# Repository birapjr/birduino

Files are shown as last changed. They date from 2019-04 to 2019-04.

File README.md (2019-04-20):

# birduino
Prototype board for common projects

Current version: 1.1

The PCB images:

3D view

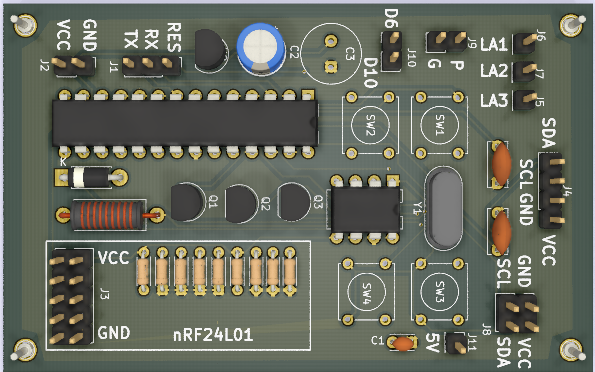
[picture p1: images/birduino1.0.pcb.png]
birduino 1.0 PCB


Front

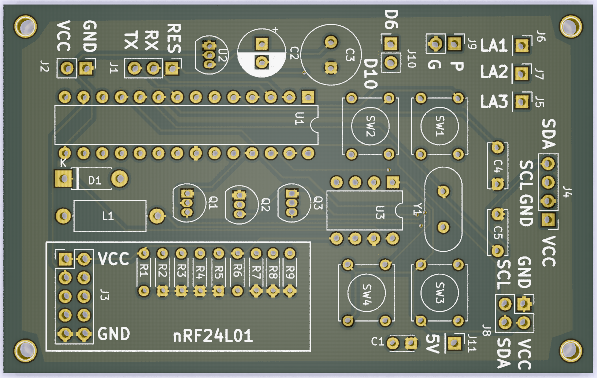
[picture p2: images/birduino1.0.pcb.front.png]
birduino 1.0 PCB front


Back

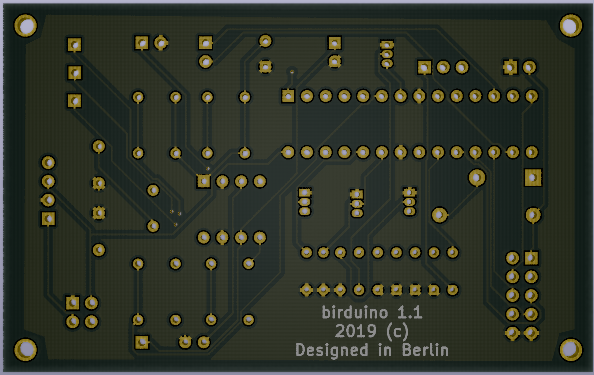
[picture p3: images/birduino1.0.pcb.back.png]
birduino 1.0 PCB back


Main features:

  * Microcontroller: ATMEGA328
  * Main voltage: 3.7 V
  * Radio card: nRF24L01
  * Sensor: Temperature DS18B20
  * Display: OLED
  * Buttons: 4
  * Setup output: 5V
  * Power controls: 3 MOSFET 2N7000
  * Analog reader: 1 pin at J9
  * Free pins: 2, D6 and D10
  * Programming: Onboard serial programming

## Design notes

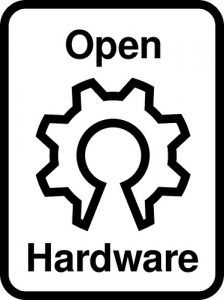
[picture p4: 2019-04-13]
images/OpenHardware.jpg

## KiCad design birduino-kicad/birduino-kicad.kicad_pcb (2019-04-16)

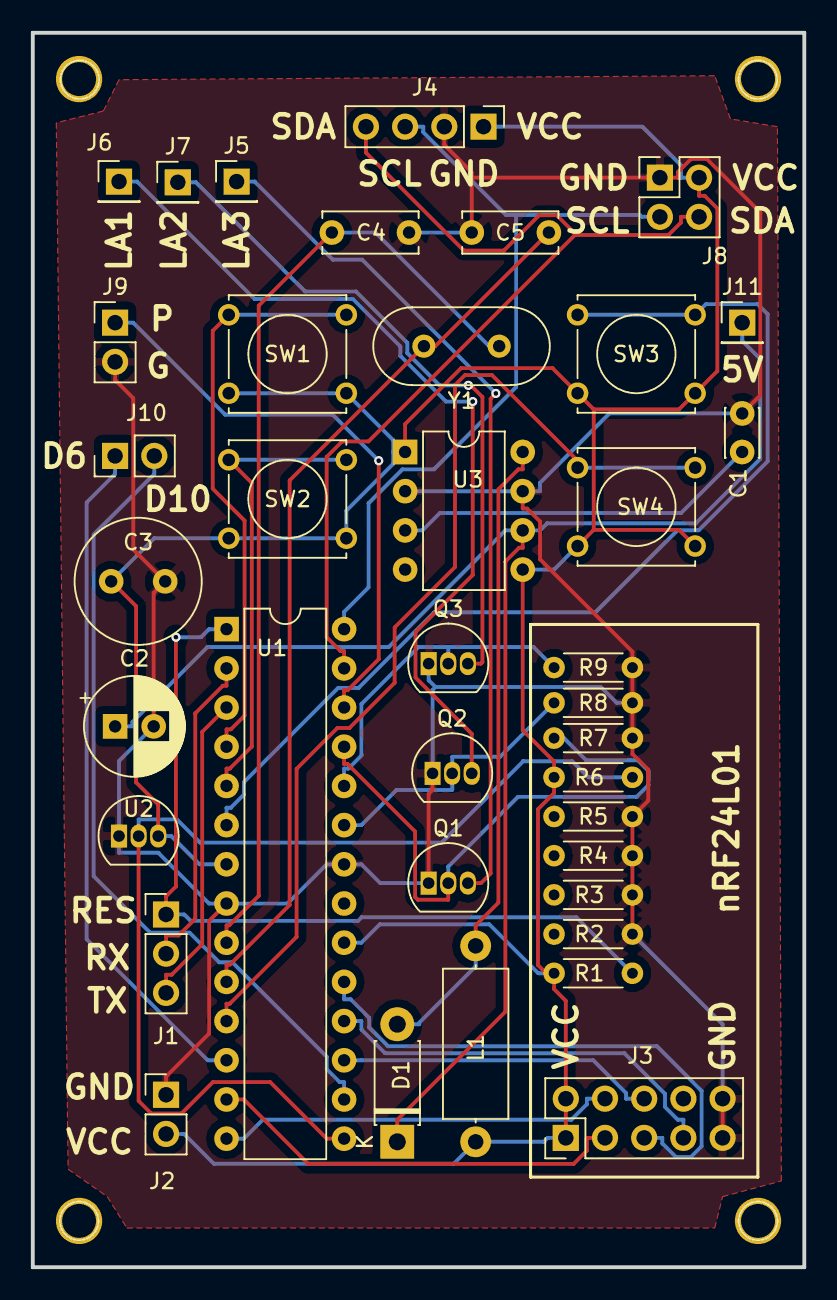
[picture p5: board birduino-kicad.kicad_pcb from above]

Board: 2 copper layers, 50.0 x 80.0 mm, 38 parts (0 on the bottom side), 31 nets.

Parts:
C1: 0.1uF; C_Disc_D3.0mm_W2.0mm_P2.50mm
C2: 100uF; CP_Radial_D6.3mm_P2.50mm
C3: 150uF; C_Radial_D8.0mm_H7.0mm_P3.50mm
C4, C5: 22uF; C_Disc_D6.0mm_W2.5mm_P5.00mm
D1: 1N5817; D_DO-41_SOD81_P7.62mm_Horizontal
J1: Conn_01x03_Male; PinHeader_1x03_P2.54mm_Vertical
J2, J10: Conn_01x02_Male; PinHeader_1x02_P2.54mm_Vertical
J3: Conn_02x05_Odd_Even; PinHeader_2x05_P2.54mm_Vertical
J4: Conn_01x04; PinHeader_1x04_P2.54mm_Vertical
J5, J6, J7, J11: Conn_01x01_Male; PinHeader_1x01_P2.54mm_Vertical
J8: Conn_02x02_Odd_Even; PinHeader_2x02_P2.54mm_Vertical
J9: Conn_01x02; PinHeader_1x02_P2.54mm_Vertical
L1: 22uH; L_Axial_L9.5mm_D4.0mm_P12.70mm_Horizontal_Fastron_SMCC
Q1, Q2, Q3: 2N7000; TO-92_Inline
R1, R2, R3, R4, R5, R7, R8, R9: 10k; R_Axial_DIN0204_L3.6mm_D1.6mm_P5.08mm_Horizontal
R6: 4.7k; R_Axial_DIN0204_L3.6mm_D1.6mm_P5.08mm_Horizontal
SW1, SW2, SW3, SW4: SW_Push_Dual; SW_Tactile_Straight_KSA0Axx1LFTR
U1: ATMEGA328-PU; DIP-28_W7.62mm
U2: DS18B20; TO-92_Inline
U3: MAX756CPA; DIP-8_W7.62mm
Y1: Crystal; Crystal_HC49-4H_Vertical

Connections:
/StepUp5V/5V: C2.1, D1.1, J11.1, U3.6
BT1: SW1.1, U1.4
BT2: SW2.1, U1.5
BT3: SW3.1, U1.6
BT4: SW4.1, U1.11
CE: J3.3, U1.13
CSN: J3.4, U1.14
FREE: J10.1, U1.12
FREE2: J10.2, U1.16
GND: C1.2, C2.2, C3.2, C4.2, C5.1, J2.1, J3.9, J3.10, J4.2, J8.1, J9.2, Q1.1, Q2.1, Q3.1, R2.1, R3.1, R4.1, R5.1, R7.2, R8.2, R9.2, U1.8, U1.22, U2.1, U3.2, U3.7
LED1: Q2.2, R8.1, U1.23
LED2: Q3.2, R9.1, U1.24
LED3: Q1.2, R7.1, U1.25
MI: J3.7, U1.18
MO: J3.6, U1.17
unnamed: C1.1, U3.3
unnamed: D1.2, L1.2, U3.8
unnamed: J1.1, R1.1, U1.1
unnamed: J1.2, U1.2
unnamed: J1.3, U1.3
unnamed: J5.1, Q1.3
unnamed: J6.1, Q2.3
unnamed: J7.1, Q3.3
PUMP: J9.1, U1.26
SCK: J3.5, U1.19
SCL: J4.3, J8.3, U1.28
SDA: J4.4, J8.4, U1.27
TEMP: R6.1, U1.15, U2.2
VCC: C3.1, J2.2, J3.1, J3.2, J4.1, J8.2, L1.1, R1.2, R6.2, SW1.2, SW2.2, SW3.2, SW4.2, U1.7, U1.20, U2.3, U3.1, U3.5
XTAL1: C4.1, U1.9, Y1.1
XTAL2: C5.2, U1.10, Y1.2

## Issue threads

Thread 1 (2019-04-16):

No outlines and no solder masques

birapjr, 2019-04-16:
Error on fabrication design at version 1.0. Missing outlines and solder masques.

birapjr, 2019-04-16:
Close with PR Fix issue nr 1 #2

Closed 2019-04-16.

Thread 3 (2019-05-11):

Bottons are not connected to pullup registor

birapjr, 2019-05-11:
On the board design the Buttons connections from the Atmega chip are not connected to the pullup registor that connects to ground.

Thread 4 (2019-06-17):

Resistor footprint to small

birapjr, 2019-06-17:
The resistor footprint are too small for the standards resistor size as discrete components.

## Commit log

2019-02-13 feat: Initial KiCad project
    [birduino-kicad.kicad_pcb, birduino-kicad.sch]
2019-02-19 feat: Added more components to the board
    [birduino-kicad.kicad_pcb, birduino-kicad.sch]
2019-02-25 feat: add radio card connections, added the first routing of vias, added backside label.
    [birduino-kicad.dsn, birduino-kicad.kicad_pcb, birduino-kicad.sch]
2019-02-27 feat: add 4 button to board
    [birduino-kicad.sch]
2019-03-04 feat: add footprint to the buttons, new routing with butons.
    [birduino-kicad.dsn, birduino-kicad.kicad_pcb, birduino-kicad.sch]
2019-03-05 feat: add display to board
    [birduino-kicad.dsn, birduino-kicad.kicad_pcb, birduino-kicad.sch]
2019-03-11 feat: migrate to Kicad 5, add LEDs control, add temperature sensor.
    [birduino-kicad.dsn, birduino-kicad.kicad_pcb, birduino-kicad.sch]
2019-03-25 feat: add new sensors and components
    [birduino-kicad.dsn, birduino-kicad.kicad_pcb, birduino-kicad.sch]
2019-04-07 feat: First final version 1.0. 3D image added to readme
    [StepUp5V.sch, birduino-kicad.dsn, birduino-kicad.kicad_pcb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]
2019-04-13 feat: added Crytal to PCB. Added new images to readme.
    [StepUp5V.sch, birduino-kicad.dsn, birduino-kicad.kicad_pcb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]
2019-04-14 feat: add fixation holes. First fabrication files. Version 1.0 closed for production.
    [birduino-kicad.kicad_pcb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]
2019-04-16 feat: Version 1.1. Better size, ground plat and proper fabrication files.
    [StepUp5V.sch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]
